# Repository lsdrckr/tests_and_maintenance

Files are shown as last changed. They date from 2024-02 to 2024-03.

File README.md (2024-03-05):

# Tests réalisés sur la carte

## Tests éléctronique
Nous avons testé au multimètre si les différents ground et 3,3V étaient reliés entre eux. Nous avons réalisés le même tests sur les différents pins du circuit.
Pour vérifier la qualité de notre soudure, nous avons vérifié qu'il n'y ai aucun court circuit et les valeurs des différents composants (résistances et capacités).
En regardant au microscope et en testant, on a remarqué quelques courts-circuits que nous avons immédiatement resoudé.

Nous avons cependant fait un grave erreur dès le schematic de notre carte : nous avons connecté les ports SWCLK et SWDIO sur les mauvais ports, ce qui empêchait le bon fonctionnement de la carte... Nous avons dû improvisé en créant des pistes volantes pour bien les connecter.

La photo ci-dessous montre le routage de SWCLK et SWDIO sur les pins 19 et 20 du stm32f030f4. Ils ne sont là que pour garder en tête les correction à faire dans le cas d'un second prototypage.
<p align="center">
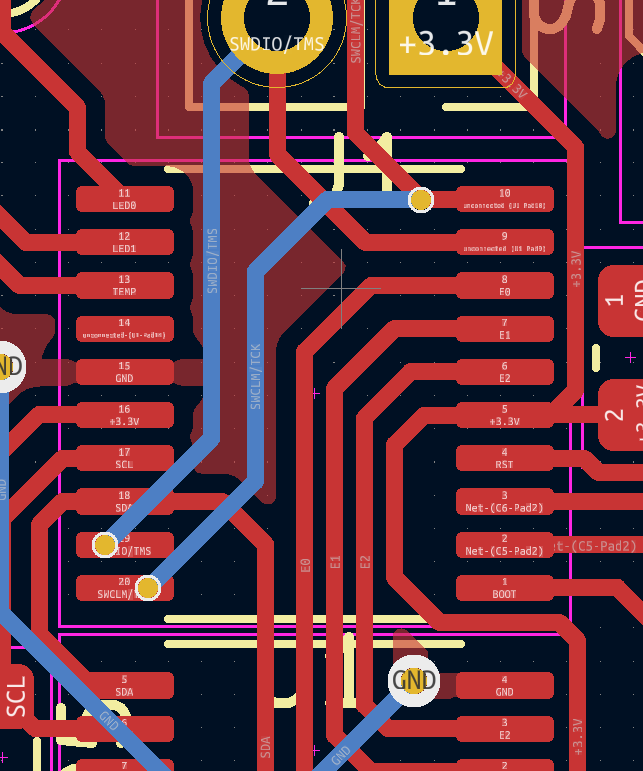
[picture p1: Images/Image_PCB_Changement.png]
Photo PCB (Les fils bleu sur les pin s 19 et 20 sont les fils Volants)
  
</p>

## Tests informatiques

A l'aide de la documentation fournis sur le site : https://linuxembedded.fr/2021/02/bare-metal-from-zero-to-blink, nous avons réaliser un Startup file nommé stm32_startup.c permettant de bien définir l'environnement pour le code main().
Il permet entre autre de gérer les handler du stm32f030f4 et d'attribuer les bonnes fonctions aux handler.

Nous avons ensuite créer le Linker cript nommé stm32_ls.ld qui permet de déterminer les adresses absolues des différentes sections en faisant référence aux informations mentionnées dans le Linker script.

Nous avons ensuite effectuer les modification necessaire pour permettre l'utilisation d'OpenOCD avec la carte : https://www.radioshuttle.de/en/turtle-en/nucleo-st-link-interface-en/

## Résultats et axes d'améliorations

Photos de la cartes finale soudées.
<p align="center">
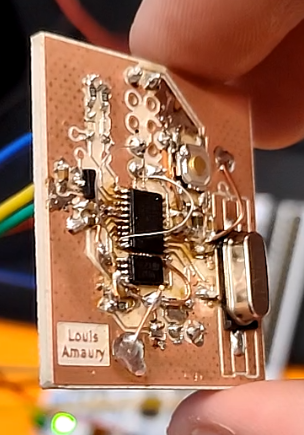
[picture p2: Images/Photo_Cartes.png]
Cartes_soudées_finale
  
</p>

Photos de l'écran lors du lancement de la commande make load.
<p align="center">
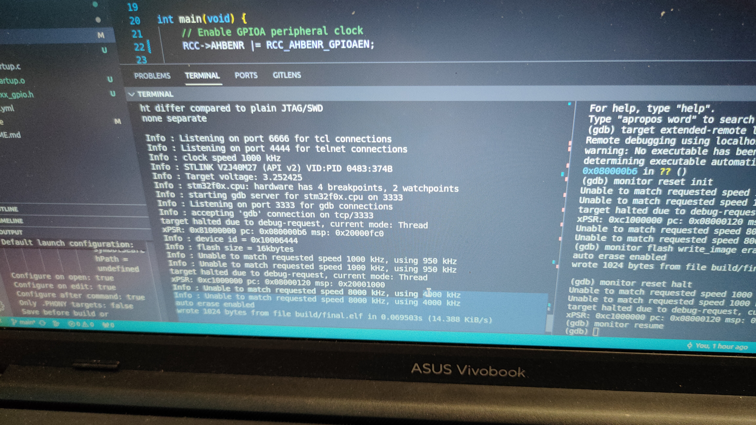
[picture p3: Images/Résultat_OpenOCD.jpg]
Résultat_OpenOCD
  
</p>
On observe bien la bonne détection de la carte.

Vidéo de la carte lors du test avec OpenOCD.
<p align="center">
  Démo_OpenOCD
</p>

Nous avons trouver ce projet fort enrichissant mais il manque à notre sens, cruellement de temps pour pouvoir effectuer le code et tous les tests unitaires nécessaire au test complet de la carte. Cependant le projet fût très enrichissant et à permis de mettre en pratique les connaissances vues en cours de TMS.

Le pipeline du Gitlab-CI se résume à un cpp-check suivi d'une étape de build et d'une étape de lint.

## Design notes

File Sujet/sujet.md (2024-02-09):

# Project test & maintenance of an embedded system

The small project consist in the design and manufacturing of a small embedded system including a microcontroler [ARM](https://www.arm.com/) of the range [STM32 from STMicroelectronics](https://www.st.com/en/microcontrollers-microprocessors/stm32-32-bit-arm-cortex-mcus.html), some auxiliary components, and teh embedded firmware.The emphasis will be on the meticulous design of both the hardware and the software to simplify pre-production testing and maintenance of the object during its lifetime.

Indeed, before large scale manufacturing, the design lab decide to realize a first prototype to fully debug the object.

The project will be carried out in four main phases:
1. Hardware design, including PCB and the documentation for a future production;
2. PCB testing, component assembly and basic hardware debugging;
3. Design of the embedded firmware, unsing good practices and CI;
4. Test of the embedded system (hardware + software), using a JTAG debugger.

## Hardware design

The hardware design consist in the design of the schematic, of the PCB and the generation all the documentation for a further mass-production, using KiCad.

The embedded system is made of :
* [a STM32F030F4 microcontroler](https://www.st.com/en/microcontrollers-microprocessors/stm32f030f4.html);
* [a M24C01 serial EEPROM memory](https://www.st.com/en/memories/m24c01-r.html) for configuration backup;
* [a MCP9700 temperature sensor](https://www.microchip.com/en-us/product/mcp9700) to get data.
* all other components for good operation (decoupling capacitors, leds, connectors, ...)

After the schematic design and entry (hierarchy should be used for better readability), you should add the testing points at critical signal levels. They will be used to test the PCB after its fabrication and after the component assembly. The extra layers in PCB design can be use to add information.

The documentation for the production will be added to the project, including schematic, PCB fabrication files and pick and place files.  

## Hardware fabrication and debug

The first prototype will be manufactured at Polytech Lille. The PCB production file should be sent to eei.polytech-lille.net. When received, the PCB will be inspected (optical inspection and rough electrical tests).

The assembly will be done step by step with documented tests at the end of each phase.

## Embedded software design

The embedded software will be design unsing the good practices seen before and is divided in diffeent steps, in between the next phase (ES development and design):
* the first step is to write the configuration part of the microprocessor. It consists in the definition of the vector table, initialization of the stack and the BSS segment;
* the second is to write a simple software to make a led blink for example;
* the final phase is to write specific code to manage the temperature sensor and the memory.

During this phase, do not forget to instrument your code to ease the debug.

## Embedded system development and design

This phase is closely linked to the previous one. You can not use CI/CD as seen before since there is an involved hardware part.

To be able to realize test close to unit test, you will use a [JTAG debugger](https://www.st.com/en/development-tools/st-link-v2.html) in conjunction with GDB (the GNU Debugger) and OpenOCD. These tools allow to execute the firmware and monitor the internal state of the microcontroler.

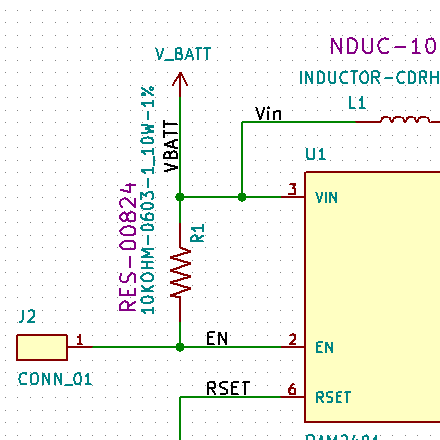
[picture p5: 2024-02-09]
Kicad/PCB_TMS/SparkFun-KiCad-Libraries-main/Pre_v7/Documentation/Pictures/eeschema.png

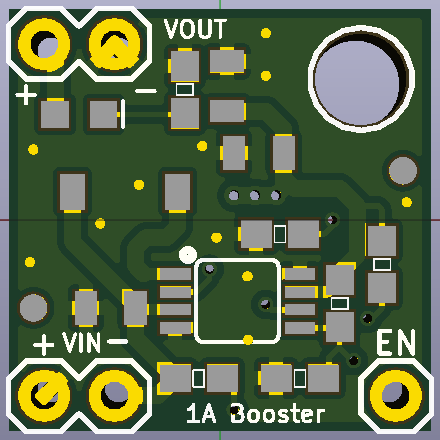
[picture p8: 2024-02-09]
Kicad/PCB_TMS/SparkFun-KiCad-Libraries-main/Pre_v7/Documentation/Pictures/ExampleGreen3DView.png

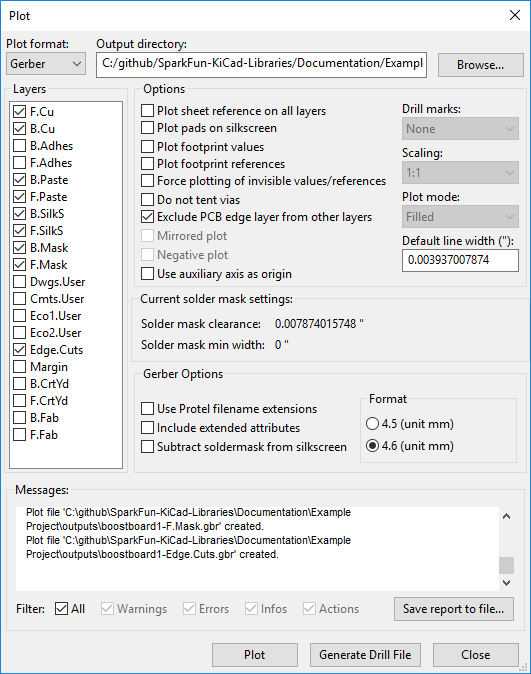
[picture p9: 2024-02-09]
Kicad/PCB_TMS/SparkFun-KiCad-Libraries-main/Pre_v7/Documentation/Pictures/PlotSettings.png

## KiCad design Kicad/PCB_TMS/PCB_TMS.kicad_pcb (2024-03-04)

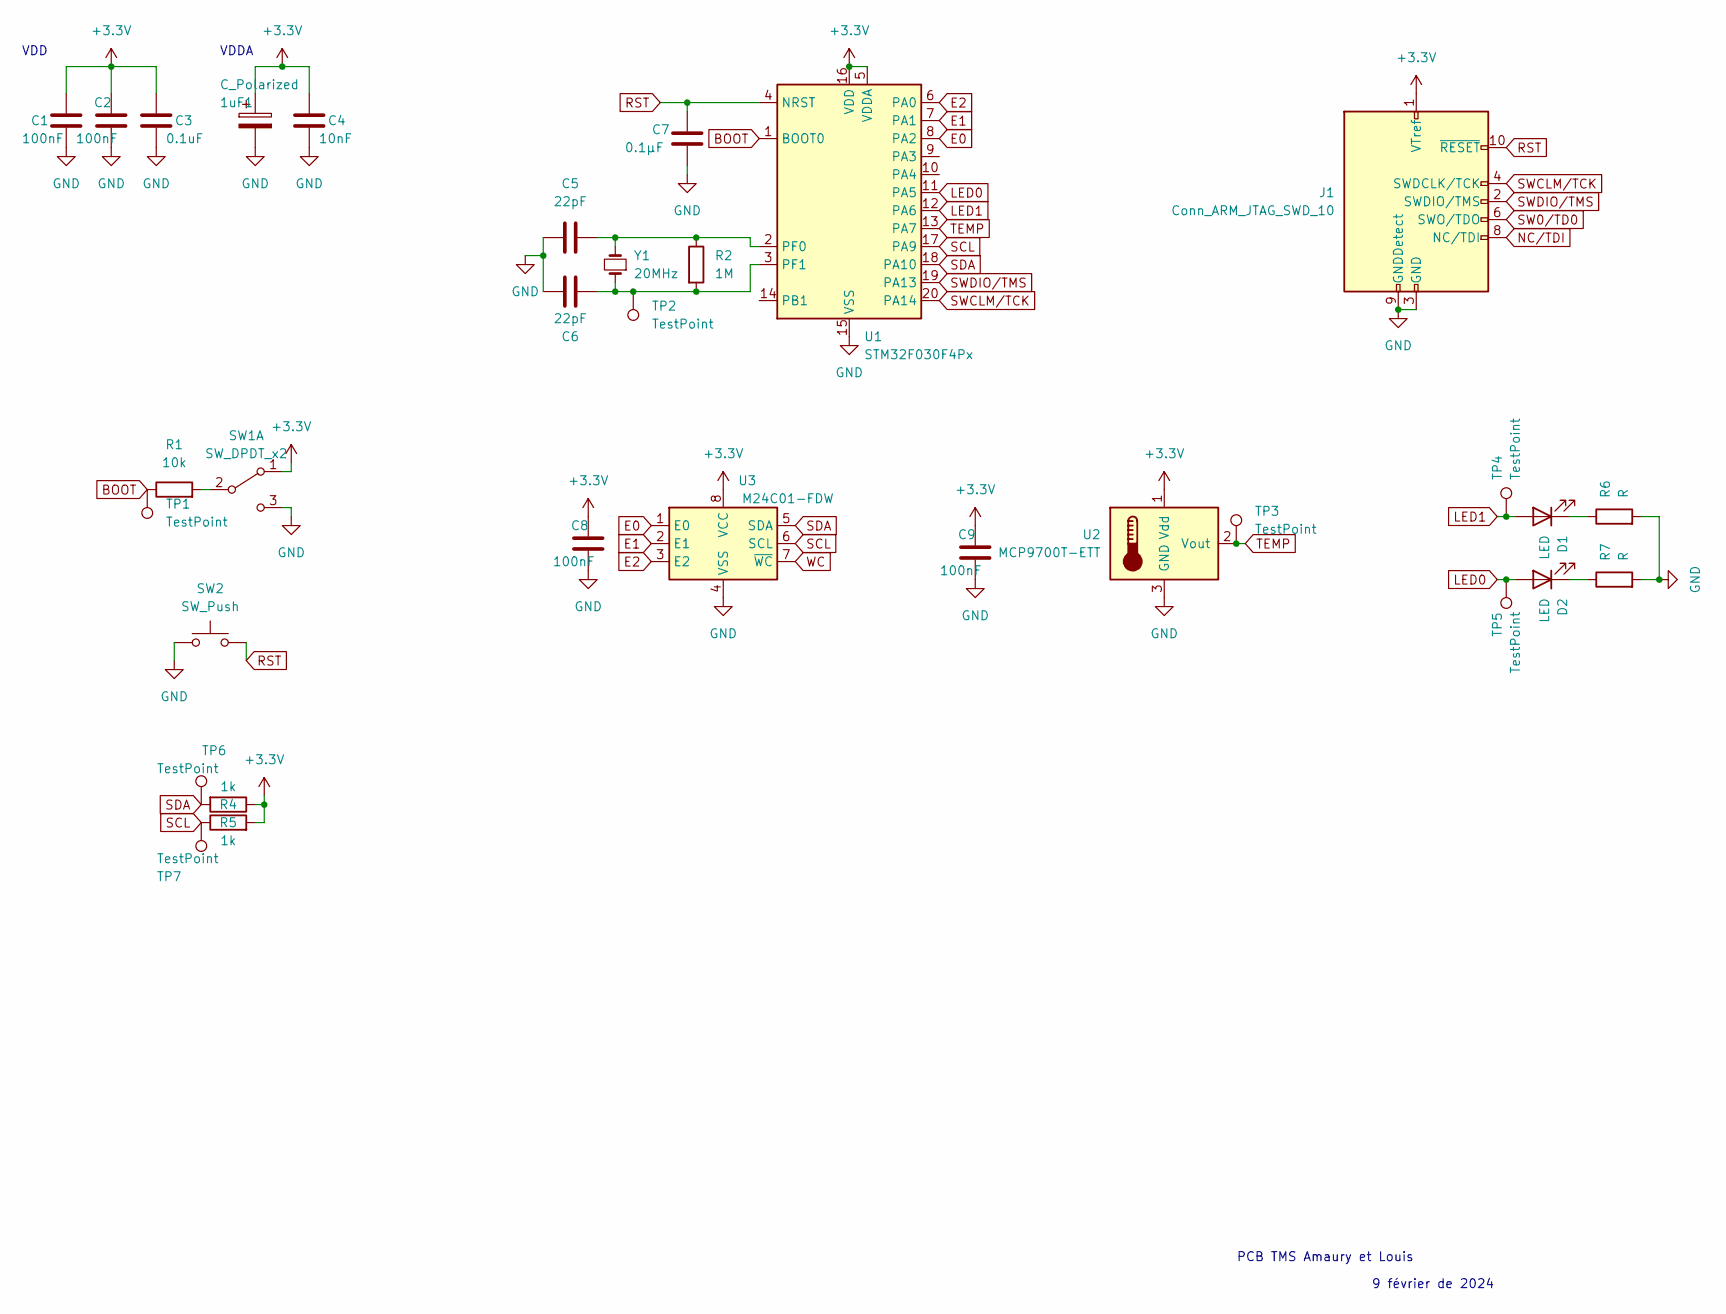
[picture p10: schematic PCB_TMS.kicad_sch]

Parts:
1uF1: C_Polarized; C_0603_1608Metric_Pad1.08x0.95mm_HandSolder
C1, C2, C8, C9: 100nF; C_0603_1608Metric_Pad1.08x0.95mm_HandSolder
C3: 0.1uF; C_0603_1608Metric_Pad1.08x0.95mm_HandSolder
C4: 10nF; C_0603_1608Metric_Pad1.08x0.95mm_HandSolder
C5, C6: 22pF; C_0603_1608Metric_Pad1.08x0.95mm_HandSolder
C7: 0.1µF; C_0603_1608Metric_Pad1.08x0.95mm_HandSolder
D1, D2: LED; D_0603_1608Metric_Pad1.05x0.95mm_HandSolder
J1: Conn_ARM_JTAG_SWD_10; PinHeader_2x05_P2.54mm_Vertical
R1: 10k; R_0603_1608Metric_Pad0.98x0.95mm_HandSolder
R2: 1M; R_0603_1608Metric_Pad0.98x0.95mm_HandSolder
R4, R5: 1k; R_0603_1608Metric_Pad0.98x0.95mm_HandSolder
R6, R7: R; R_0603_1608Metric_Pad0.98x0.95mm_HandSolder
SW1: SW_DPDT_x2; PinHeader_1x03_P2.54mm_Vertical
SW2: SW_Push; SW_SPST_SKQG_WithStem
TP1, TP2, TP3, TP4, TP5, TP6, TP7: TestPoint; TestPoint_Pad_D1.0mm
U1: STM32F030F4Px; TSSOP-20_4.4x6.5mm_P0.65mm
U2: MCP9700T-ETT; SOT-23
U3: M24C01-FDW; TSSOP-8_4.4x3mm_P0.65mm
Y1: 20MHz; Crystal_SMD_HC49-SD_HandSoldering

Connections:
+3.3V: 1uF1.1, C1.2, C2.2, C3.2, C4.2, C8.2, C9.2, J1.1 (VTref), R4.1, R5.2, SW1.1 (A), U1.5 (VDDA), U1.16 (VDD), U2.1 (Vdd), U3.8 (VCC)
BOOT: R1.1, TP1.1, U1.1 (BOOT0)
E0: U1.8 (PA2), U3.1 (E0)
E1: U1.7 (PA1), U3.2 (E1)
E2: U1.6 (PA0), U3.3 (E2)
GND: 1uF1.2, C1.1, C2.1, C3.1, C4.1, C5.1, C6.1, C7.1, C8.1, C9.1, J1.3 (GND), J1.5 (GND), J1.9 (GNDDetect), R6.2, R7.2, SW1.3 (C), SW2.1, U1.15 (VSS), U2.3 (GND), U3.4 (VSS)
LED0: D2.2 (A), TP5.1, U1.11 (PA5)
LED1: D1.2 (A), TP4.1, U1.12 (PA6)
NC/TDI: J1.8 (NC/TDI)
unnamed: C5.2, R2.1, U1.2 (PF0), Y1.2
unnamed: C6.2, R2.2, TP2.1, U1.3 (PF1), Y1.1
unnamed: D1.1 (K), R6.1
unnamed: D2.1 (K), R7.1
unnamed: R1.2, SW1.2 (B)
RST: C7.2, J1.10 (~RESET), SW2.2, U1.4 (NRST)
SCL: R5.1, TP7.1, U1.17 (PA9), U3.6 (SCL)
SDA: R4.2, TP6.1, U1.18 (PA10), U3.5 (SDA)
SW0/TD0: J1.6 (SWO/TDO)
SWCLM/TCK: J1.4 (SWDCLK/TCK), U1.20 (PA14)
SWDIO/TMS: J1.2 (SWDIO/TMS), U1.19 (PA13)
TEMP: TP3.1, U1.13 (PA7), U2.2 (Vout)
WC: U3.7 (~WC)

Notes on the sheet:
VDDA
9 février de 2024
VDD
PCB TMS Amaury et Louis

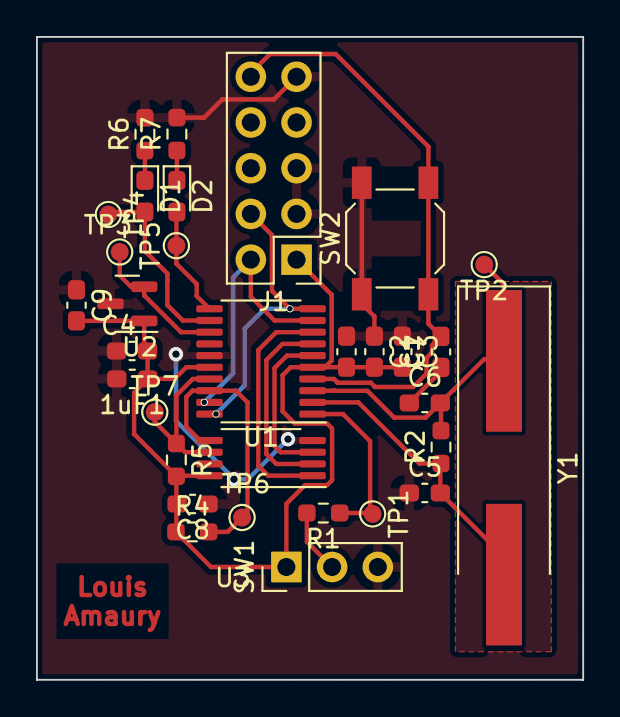
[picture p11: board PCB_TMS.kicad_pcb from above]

Board: 2 copper layers, 30.3 x 35.7 mm, 32 parts (0 on the bottom side), 19 nets.

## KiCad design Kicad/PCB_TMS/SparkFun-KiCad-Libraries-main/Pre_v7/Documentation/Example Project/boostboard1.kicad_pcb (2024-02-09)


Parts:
C1, C2, C3: 22UF-0805-6.3V-20%; 0805
D1: LED-RED0603; LED-0603
FD1, FD2: FIDUCIAL1X2; FIDUCIAL-1X2
H1: STAND-OFF
J1, J3: CONN_02; 1X02
J2: CONN_01; 1X01
JP1: JUMPER-SMT_2_NO; SMT-JUMPER_2_NO_SILK
L1: INDUCTOR-CDRH-4.7UH; INDUCTOR_2.2UH
LOGO1: SFE_LOGO_NAME_FLAME.1_INCH; SFE_LOGO_NAME_FLAME_.1
LOGO2: OSHW-LOGOS; OSHW-LOGO-S
R1: 10KOHM-0603-1_10W-1%; 0603
R2, R4: 100KOHM-0603-1_10W-1%; 0603
R3, R5: 820KOHM-0603-1_10W-1%; 0603
R6: 4.7KOHM-0603-1_10W-1%; 0603
U1: PAM2401; MSOP8

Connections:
/EN: J2.1, R1.2, U1.2 (EN)
/FB: JP1.2, R3.1, R4.2, U1.5 (FB)
/GND: C1.2, C2.2, C3.2, J1.1, J3.1, R2.2, R4.1, R6.1, U1.4 (AGND), U1.8 (PGND)
/LX: L1.P$2 (2), U1.1 (LX)
/RSET: R2.1, U1.6 (RSET)
/VBATT: C1.1, J1.2, L1.P$1 (1), R1.1, U1.3 (VIN)
/VCC: C2.1, C3.1, D1.A, J3.2, R3.2, R5.2, U1.7 (OUT)
unnamed: D1.C, R6.2
unnamed: JP1.1, R5.1

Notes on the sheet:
1A Booster
Jumper: Open for 5.0V operation Closed for 3.3V operation
Input
Output
Input Range: 0.9 to 4.75V For full output capacity, upwards of 3A may be required. For max operation, calculate with P=IV, using 6 watts. At 3.7V, Iin = 1.62A



Board: 2 copper layers, 15.2 x 15.2 mm, 21 parts (3 on the bottom side), 9 nets.

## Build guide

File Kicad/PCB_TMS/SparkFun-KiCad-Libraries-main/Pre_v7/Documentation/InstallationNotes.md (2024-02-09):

Installation Notes
----------------

* [The KiCad site](http://kicad.org/)

**KiCad installation**

* Uninstall previous versions of KiCad
* Download KiCad stable version 4.0.5 from [http://kicad.org/download/](http://kicad.org/download/windows/) and install
* After install, you'll be prompted to install "Wings 3D", check this box to be redirected to [http://www.wings3d.com/](http://www.wings3d.com/)
* Download and install the stable release 2.1.5

**Using the libraries**

* Create a local project (this is necessary because projects hold library path information)
* Open the "Schematic Library Editor"
* Prefrences -> Component Libraries
  * Remove all libraries from list
  * Add -> navigate to SparkFun-KiCad-Libraries -> select all .lib files -> open, then hit OK
  * Test by selecting an active library.  All sparkfun libraries should be displayed.  Close the library editor
* Open the "PCB Footprint Editor"
* Preferences -> Footprint Library Manager
  * Remove all (if any) libraries, hit OK
* Preferences -> Footprint Libraries Wizard
  * Next (files on my computer)
  * Navigate to SparkFun-KiCad-Libraries -> select all .mod files and hit ok
  * Next
  * Select for this project only
  * Next
  * Close the editor
* Save the project (Green arrow into extern HDD icon, no menu exists)

Now, this project is linked to the libraries.  Open a schematic and place components.  See KiCad enginursday post for converting from schematic into board (Note: You need to have nets for this to work... not just unconnected components)

**License Information**

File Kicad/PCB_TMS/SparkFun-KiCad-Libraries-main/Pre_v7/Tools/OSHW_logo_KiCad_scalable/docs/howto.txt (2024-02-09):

How to make your own:
---------------------

Watch / read this first:

* http://www.kicad.org/display/KICAD/Videos+by+zupnikal
  * PCB layout with KiCad => https://www.youtube.com/playlist?list=PL67B2290F4C62B5F2
    * KiCad #1 - Mounting hole clearance and cut-out zone in the copper pour
    * KiCad #2 - Solder mask clearance
    * KiCad #3 - Using 'FreeRoute' to create a simple board
    * KiCad #4 - Adding the OSHW logo to your layout
    * KiCad #5 - Using custom logos in your design

The last two videos should be helpful for how to create a custom .emp file from images.

* http://www.re-innovation.co.uk/web12/index.php/en/blog-75/230-adding-logo-to-kicad

If you use linux (which you should), you don't have to use the online-scaler. Just use the scripts!

---

* Create a folder to hold your new footprint library.
* Copy the scripts 'make_lib.sh' and 'scale.pl' into that folder.
* Make sure these files are executable (chmod u+x ...).
* Copy your custom .emp file into that foler.

* Run the 'make_lib.sh' script as follows:

./make_lib.sh input-file.emp lib-name.mod START END

START and END are placeholders for positive integer numbers (1,2,3...) that determine
the range of created footprint sizes. The units are metric (mm).

The 'lib-name.mod' file will show up in the 'lib' sub-folder. Add it to your pcbnew
library settings as usual.

Footprints that are created for back-layers are automagically mirrored horizontally.
To place them onto a back-layer, hover the mouse-pointer over them and press 'f' for 'flip'.

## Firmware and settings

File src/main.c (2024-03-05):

#include <stdint.h>

// register address
#define RCC_BASE 0x40021000
#define GPIOC_BASE 0x40011000
#define RCC_APB2ENR *(volatile uint32_t *)(RCC_BASE + 0x18)
#define GPIOC_CRH *(volatile uint32_t *)(GPIOC_BASE + 0x04)
#define GPIOC_ODR *(volatile uint32_t *)(GPIOC_BASE + 0x0C)

// bit fields
#define RCC_IOPCEN (1<<4)
#define GPIOC13 (1UL<<13)


int main(void)
{
return 0;
}

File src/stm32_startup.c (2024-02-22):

#include <stdint.h>

#define SRAM_START 0x20000000U
#define SRAM_SIZE  (4U * 1024U)            /* 20 kb       */
#define SRAM_END   ((SRAM_START) + (SRAM_SIZE))

#define STACK_START SRAM_END

extern uint32_t _etext;
extern uint32_t _sdata;
extern uint32_t _edata;
extern uint32_t _la_data;
extern uint32_t _sbss;
extern uint32_t _ebss;

int main(void);

void Reset_Handler(void);
void NMI_Handler(void)                       __attribute__ ((weak,alias("Default_Handler")));
void HardFault_Handler(void)                 __attribute__ ((weak,alias("Default_Handler")));
void SVCall_Handler(void)                    __attribute__ ((weak,alias("Default_Handler")));
void PendSV_Handler(void)                    __attribute__ ((weak,alias("Default_Handler")));
void SysTick_Handler(void)                   __attribute__ ((weak,alias("Default_Handler")));
void WWDG_Handler(void)                      __attribute__ ((weak,alias("Default_Handler")));
void Reserved_Handler(void)                  __attribute__ ((weak,alias("Default_Handler")));
void RTC_Handler(void)                       __attribute__ ((weak,alias("Default_Handler")));
void FLASH_Handler(void)                     __attribute__ ((weak,alias("Default_Handler")));
void RCC_Handler(void)                       __attribute__ ((weak,alias("Default_Handler")));
void EXTI0_1_Handler(void)                   __attribute__ ((weak,alias("Default_Handler")));
void EXTI2_3_Handler(void)                   __attribute__ ((weak,alias("Default_Handler")));
void EXTI4_15_Handler(void)                  __attribute__ ((weak,alias("Default_Handler")));
void DMA_CH1_Handler(void)                   __attribute__ ((weak,alias("Default_Handler")));
void DMA_CH2_3_Handler(void)                 __attribute__ ((weak,alias("Default_Handler")));
void DMA_CH4_5_Handler(void)                 __attribute__ ((weak,alias("Default_Handler")));
void ADC_Handler(void)                       __attribute__ ((weak,alias("Default_Handler")));
void TIM1_BRK_UP_TRG_COM_Handler(void)       __attribute__ ((weak,alias("Default_Handler")));
void TIM1_CC_Handler(void)                   __attribute__ ((weak,alias("Default_Handler")));
void TIM3_Handler(void)                      __attribute__ ((weak,alias("Default_Handler")));
void TIM6_Handler(void)                      __attribute__ ((weak,alias("Default_Handler")));
void TIM14_Handler(void)                     __attribute__ ((weak,alias("Default_Handler")));
void TIM15_Handler(void)                     __attribute__ ((weak,alias("Default_Handler")));
void TIM16_Handler(void)                     __attribute__ ((weak,alias("Default_Handler")));
void TIM17_Handler(void)                     __attribute__ ((weak,alias("Default_Handler")));
void I2C1_Handler(void)                      __attribute__ ((weak,alias("Default_Handler")));
void I2C2_Handler(void)                      __attribute__ ((weak,alias("Default_Handler")));
void SPI1_Handler(void)                      __attribute__ ((weak,alias("Default_Handler")));
void SPI2_Handler(void)                      __attribute__ ((weak,alias("Default_Handler")));
void USART1_Handler(void)                    __attribute__ ((weak,alias("Default_Handler")));
void USART2_Handler(void)                    __attribute__ ((weak,alias("Default_Handler")));
void USART3_4_5_6_Handler(void)              __attribute__ ((weak,alias("Default_Handler")));
void USB_Handler(void)                       __attribute__ ((weak,alias("Default_Handler")));



uint32_t vectors[] __attribute__ ((section(".isr_vector"))) ={
    STACK_START,
    (uint32_t) &Reset_Handler,
    (uint32_t) &HardFault_Handler,
    (uint32_t) &SVCall_Handler,
    (uint32_t) &PendSV_Handler,
    (uint32_t) &SysTick_Handler,
    (uint32_t) &WWDG_Handler,
    0,
    (uint32_t) &Reserved_Handler,
    (uint32_t) &RTC_Handler,
    (uint32_t) &FLASH_Handler,
    (uint32_t) &RCC_Handler,
    (uint32_t) &EXTI0_1_Handler,
    (uint32_t) &EXTI2_3_Handler,
    (uint32_t) &EXTI4_15_Handler,
    0,
    (uint32_t) &DMA_CH1_Handler,
    (uint32_t) &DMA_CH2_3_Handler,
    (uint32_t) &DMA_CH4_5_Handler,
    (uint32_t) &ADC_Handler,
    (uint32_t) &TIM1_BRK_UP_TRG_COM_Handler,
    (uint32_t) &TIM1_CC_Handler,
    0,
    (uint32_t) &TIM3_Handler,
    (uint32_t) &TIM6_Handler,
    0,
    (uint32_t) &TIM14_Handler,
    (uint32_t) &TIM15_Handler,
    (uint32_t) &TIM16_Handler,
    (uint32_t) &TIM17_Handler,
    (uint32_t) &I2C1_Handler,
    (uint32_t) &I2C2_Handler,
    (uint32_t) &SPI1_Handler,
    (uint32_t) &SPI2_Handler,
    (uint32_t) &USART1_Handler,
    (uint32_t) &USART2_Handler,
    (uint32_t) &USART3_4_5_6_Handler,
    0,
    (uint32_t) &USB_Handler,
};

void Reset_Handler(void)
{
  /* Copy .data section to SRAM   */
  uint32_t size = (uint32_t) &_edata - (uint32_t) &_sdata;

  uint8_t *pSrc = (uint8_t *) &_etext;     /* Flash to ...   */
  uint8_t *pDst = (uint8_t *) &_la_data;   /* ... SRAM       */

  for (uint32_t i=0; i< size; i++) {
    *pDst++ = *pSrc++;
  }


  /* Initilaze the .bss zone to 0   */
  size = (uint32_t) &_ebss - (uint32_t) &_sbss;

  pDst = (uint8_t *) &_sbss;        /* Into SRAM            */

  for (uint32_t i=0; i < size; i++) {
    *pDst++ = 0;
  }

  //__libc_init_array();

  main();
}

void Default_Handler(void) {
    while (1);
}

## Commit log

2024-02-09 Création du projet kicad
    [PCB_TMS.kicad_pcb, PCB_TMS.kicad_sch]
2024-02-09 Fin schematic
    [PCB_TMS.kicad_sch, _saved_boostboard1.sch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]
2024-02-09 Début routage
    [PCB_TMS.kicad_pcb, PCB_TMS.kicad_sch]
2024-02-17 Routage v1
    [PCB_TMS.kicad_pcb]
2024-02-19 Changement d'empreintes
    [PCB_TMS.kicad_pcb, PCB_TMS.kicad_sch]
2024-02-20 PCB Routage fini
    [PCB_TMS.kicad_pcb, PCB_TMS.kicad_sch]
2024-02-21 Génération gerber
    [PCB_TMS-B_Cu.gbr, PCB_TMS-B_Mask.gbr, PCB_TMS-B_Paste.gbr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]
2024-02-21 Génération gerber (bonne)
    [PCB_TMS-B_Cu.gbr, PCB_TMS-B_Mask.gbr, PCB_TMS-B_Paste.gbr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]
2024-03-04 correction PCB
    [PCB_TMS.kicad_pcb, PCB_TMS.kicad_sch]

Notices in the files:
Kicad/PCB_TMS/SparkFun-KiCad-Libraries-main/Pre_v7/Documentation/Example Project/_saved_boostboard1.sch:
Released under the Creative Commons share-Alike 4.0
